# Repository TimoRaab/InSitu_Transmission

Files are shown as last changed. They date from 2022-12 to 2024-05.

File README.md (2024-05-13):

# InSitu_Transmission

Files for In-Situ Transmission Spin Coating Setup from the PhD Thesis "In-Situ Characterization of Film Formation in Solution-Processed Solar Cells" from Timo Raab, Universität Konstanz, 2022.

File setup of in-situ Data
v09+

The files are stored binary using the LabView WriteToBinaryFile function. For correct sizing of the arrays the dimension is stored additionally at the beginning of each file. 
For each measurement 4 files are stored:
_meas.spin (stores the real data)
_time.spin (stores the time of each data point (in 10us, standard from spectrometer))
_add.spin (additional data like dark and reference spectra, wavelength axis, start time …)

For using these binary files one has to know exactly how these are stored, as one is only interpreting bytes when reading them. One could open these files with any other program and let it try to interpret these files. If additional informations are stored in the LabView program, the interpretation of the read scripts has to be adjusted accordingly. 

The meas.spin stores each point as an „unsigned int 16“. One can imagine it as a black and white movie, in which spectrum is a picture containing its grey values. The size of the picture are the x and y direction. The length of the movie is frames. 
All of these values are stored at the beginning of each file as an „unsigned integer 32“. Therefore before reading the measurement data, first the 3 dimensions of the movie are read from the file. Afterwards the actual measurement data is read from the file. It is exactly x*y*frames datapoints read.
After reading, all these data is contained in a one dimensional array. This has to be reshaped to a correct 3-dimensional array. 

The time array is in labview a one dimensional array. It is also stored like the data, but only one dimension is written in front of the actual data and therefore has to be read before the data. The size has to be the same as the frames. The time is stored as an uint32 for better resolution and enough range.

The add.spin is the most complicated file, as multiple arrays and values are stored. 
3 dimensional array for the dark-spectrum (uint16)
3 dimensional array for the reference spectrum (uint16)
1 dimensional array for the wavelength (double)
single value for starttime (double)
single value for timeDiff (double)

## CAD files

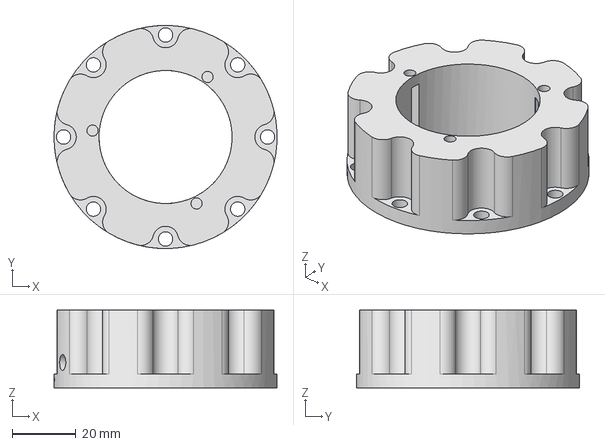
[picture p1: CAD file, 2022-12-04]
Hardware/Step/MotorHolder.stp
70.0 x 70.0 x 24.4 mm

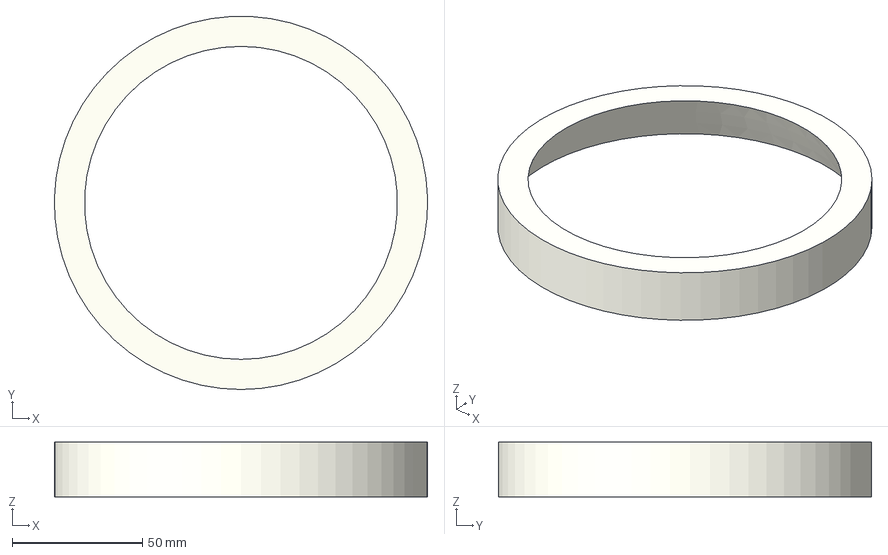
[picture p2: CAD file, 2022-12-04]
Hardware/Step/Ring.stp
143.2 x 143.2 x 21.0 mm

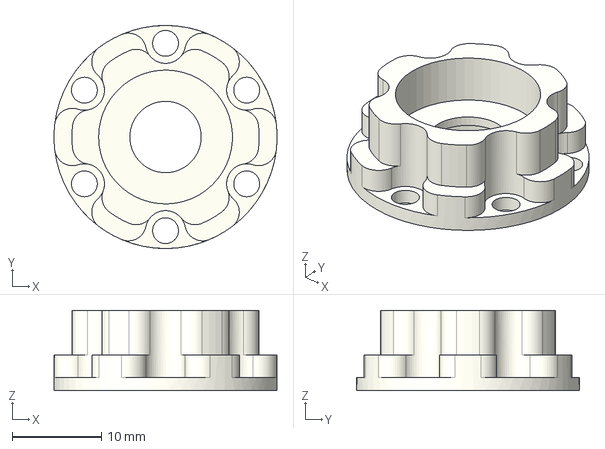
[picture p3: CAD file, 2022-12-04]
Hardware/Step/motor_top.stp
25.0 x 25.0 x 9.00 mm

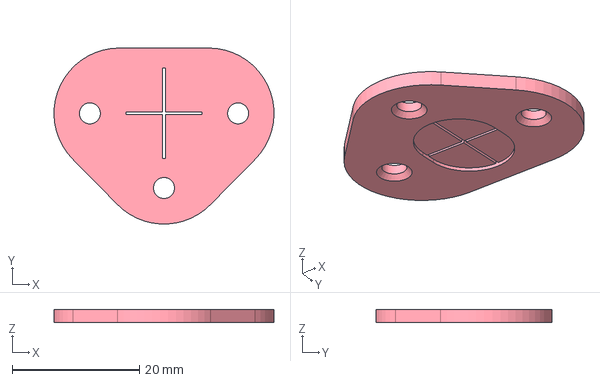
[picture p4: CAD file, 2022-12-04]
Hardware/Step/Cover.stp
34.6 x 27.7 x 2.00 mm

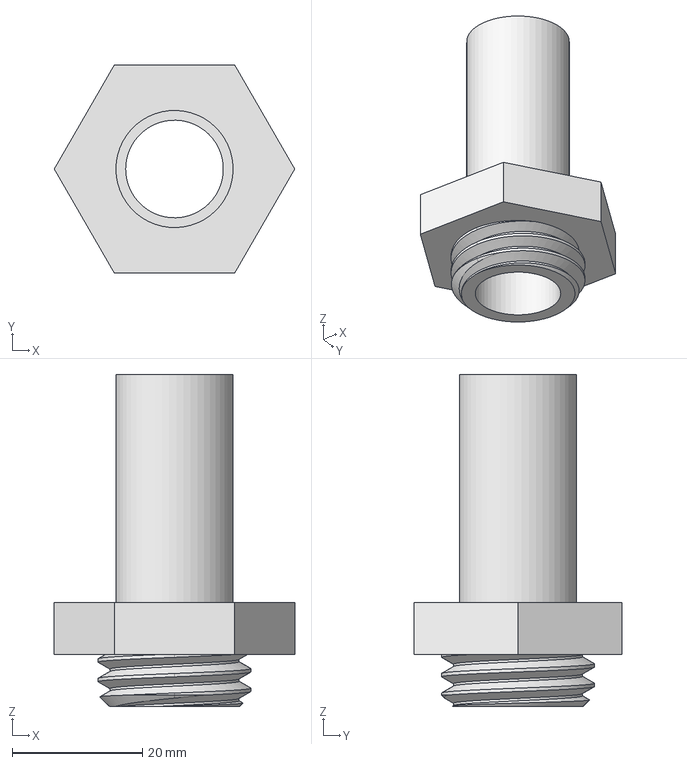
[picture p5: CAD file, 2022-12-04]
Hardware/Step/WaterAdapter.stp
37.0 x 32.0 x 51.0 mm

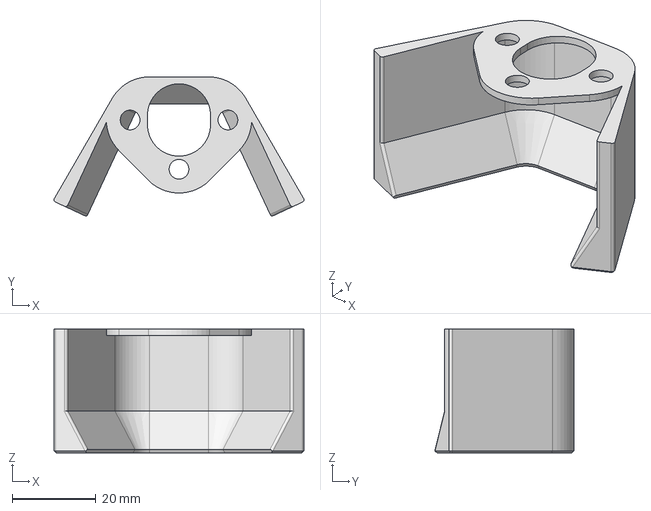
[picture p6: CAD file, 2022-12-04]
Hardware/Step/Cover_EqualPressure.stp
59.5 x 33.2 x 29.5 mm

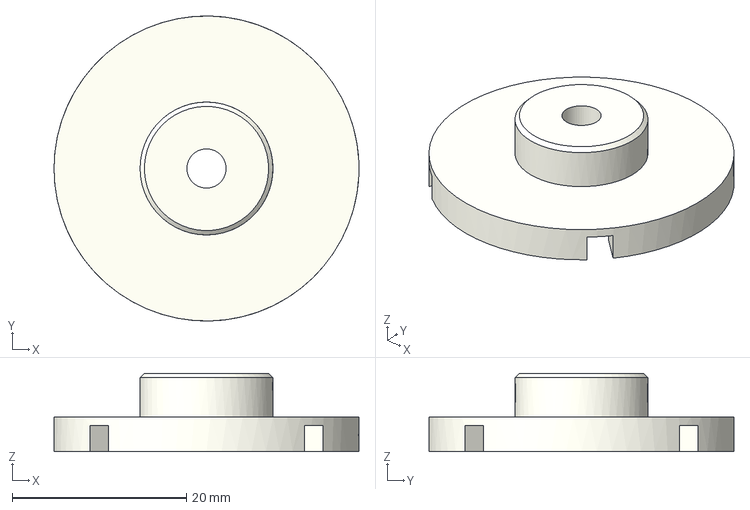
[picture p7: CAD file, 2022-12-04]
Hardware/Step/chuck_v03.stp
35.0 x 35.0 x 9.00 mm

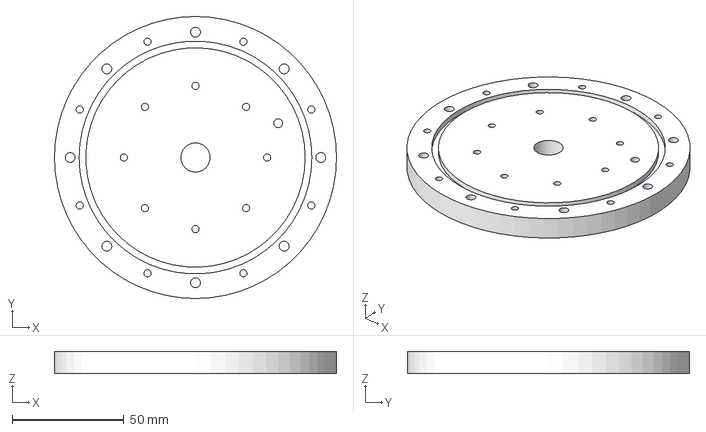
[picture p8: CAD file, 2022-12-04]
Hardware/Step/Base_Bowl_Glovebox.stp
126.0 x 126.0 x 10.0 mm

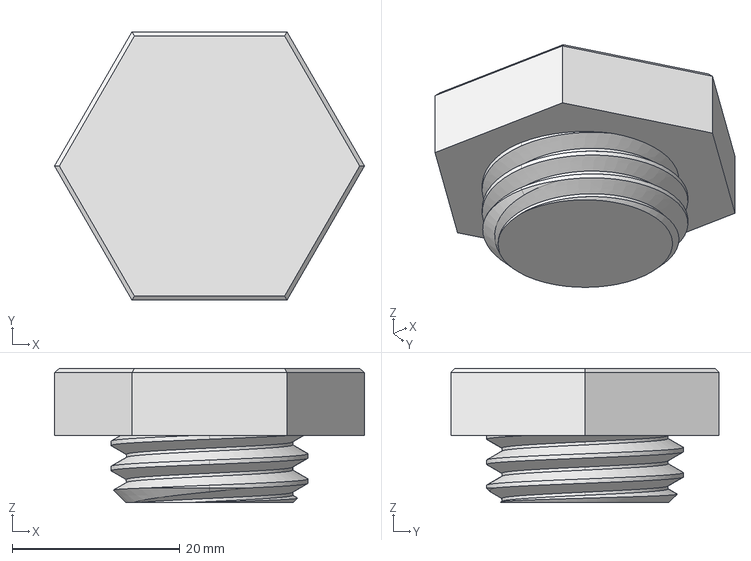
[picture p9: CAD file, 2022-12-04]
Hardware/Step/WaterAdapter_Closure.stp
37.0 x 32.0 x 16.0 mm

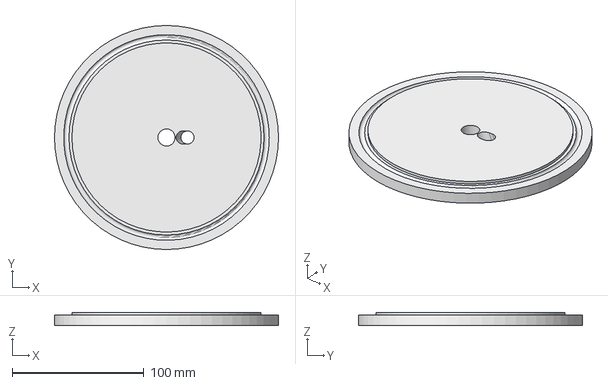
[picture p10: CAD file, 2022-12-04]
Hardware/Step/Deckel.stp
170.0 x 170.0 x 10.0 mm

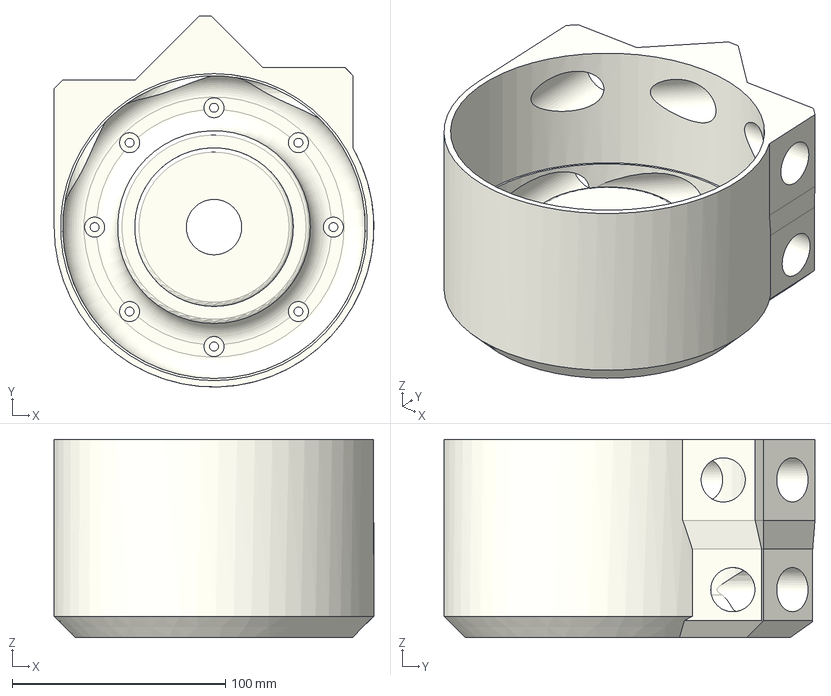
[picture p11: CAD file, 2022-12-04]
Hardware/Step/Bowl_GloveboxLike-small_ScrewingAbove.stp
150.0 x 174.0 x 93.0 mm

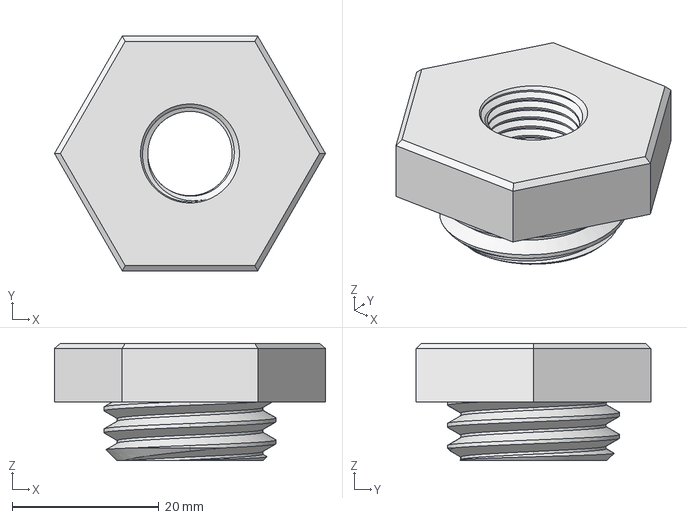
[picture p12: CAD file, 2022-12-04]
Hardware/Step/M24_2_1_4inch.stp
37.0 x 32.0 x 16.0 mm

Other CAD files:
Hardware/SpinCoaterAssembly/Base_Bowl_Glovebox.ipt
Hardware/SpinCoaterAssembly/Bowl_GloveboxLike-small_ScrewingAbove.ipt
Hardware/SpinCoaterAssembly/Cover.ipt
Hardware/SpinCoaterAssembly/Cover_EqualPressure.ipt
Hardware/SpinCoaterAssembly/Cover_Giessform.ipt
Hardware/SpinCoaterAssembly/Deckel.ipt
Hardware/SpinCoaterAssembly/M24_2_1_4inch.ipt
Hardware/SpinCoaterAssembly/MotorHolder.ipt
Hardware/SpinCoaterAssembly/OldVersions/Bowl_GloveboxLike-small_ScrewingAbove.0003.ipt
Hardware/SpinCoaterAssembly/OldVersions/Cover.0004.ipt
Hardware/SpinCoaterAssembly/OldVersions/Deckel.0004.ipt
Hardware/SpinCoaterAssembly/OldVersions/Ring.0002.ipt
Hardware/SpinCoaterAssembly/OldVersions/SpinCoaterAssembly.0003.iam
Hardware/SpinCoaterAssembly/Ring.ipt
Hardware/SpinCoaterAssembly/SpinCoaterAssembly.iam
Hardware/SpinCoaterAssembly/WaterAdapter.ipt
Hardware/SpinCoaterAssembly/WaterAdapter_Closure.ipt
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

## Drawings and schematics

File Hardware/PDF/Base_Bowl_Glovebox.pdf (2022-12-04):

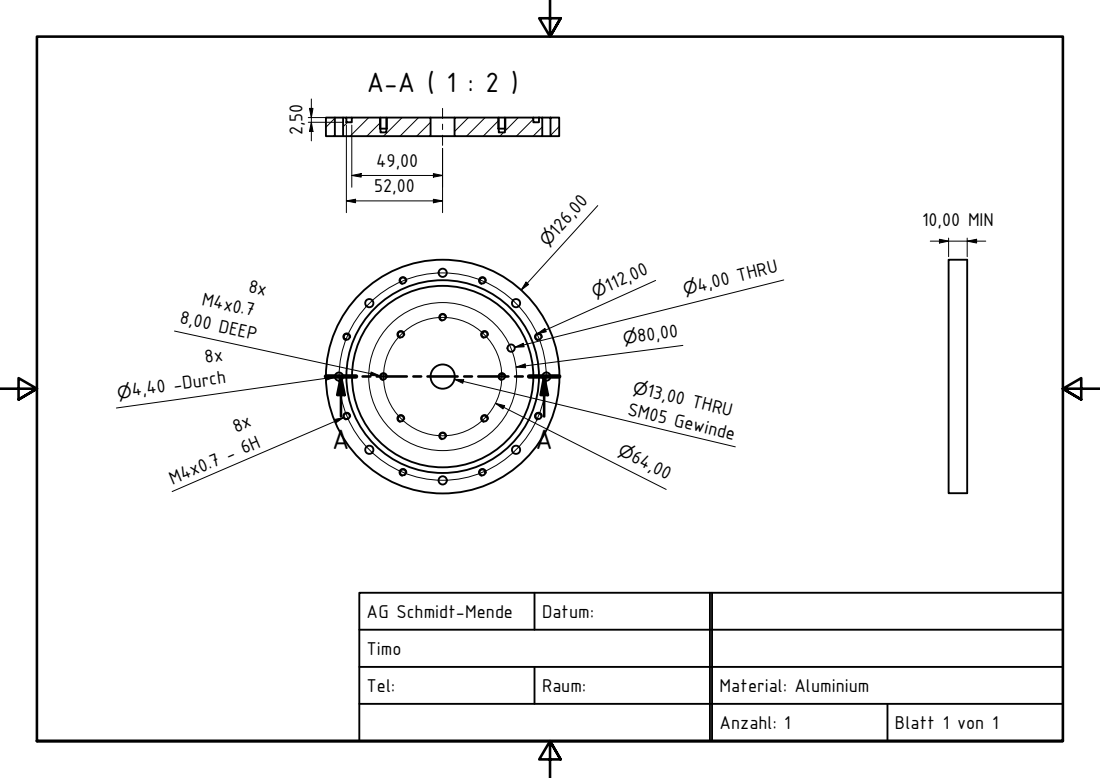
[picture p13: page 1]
10,00 MIN; 13,00 THRU 05 Gewinde; 8,00 DEEP

AG Schmidt-Mende | Datum:

Timo

Tel: | Raum: | Material: Aluminium

Anzahl: 1 | Blatt 1 von 1

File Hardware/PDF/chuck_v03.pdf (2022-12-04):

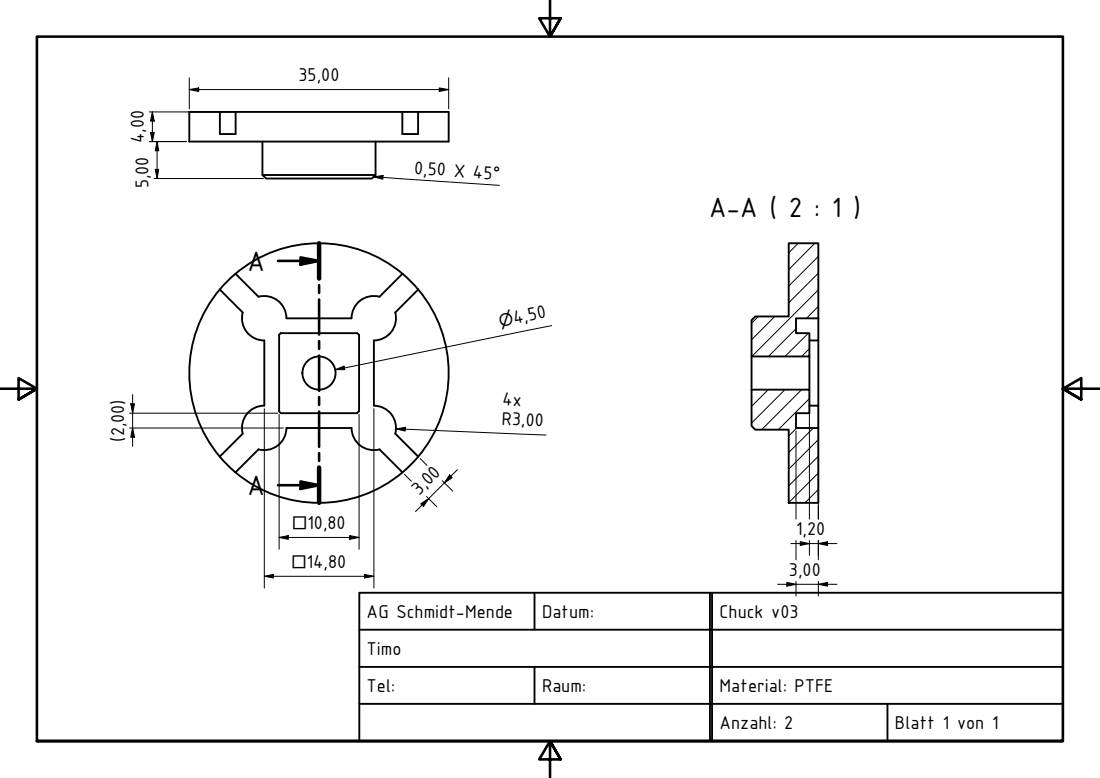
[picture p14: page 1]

AG Schmidt-Mende | Datum: | Chuck v03

Timo

Tel: | Raum: | Material: PTFE

Anzahl: 2 | Blatt 1 von 1

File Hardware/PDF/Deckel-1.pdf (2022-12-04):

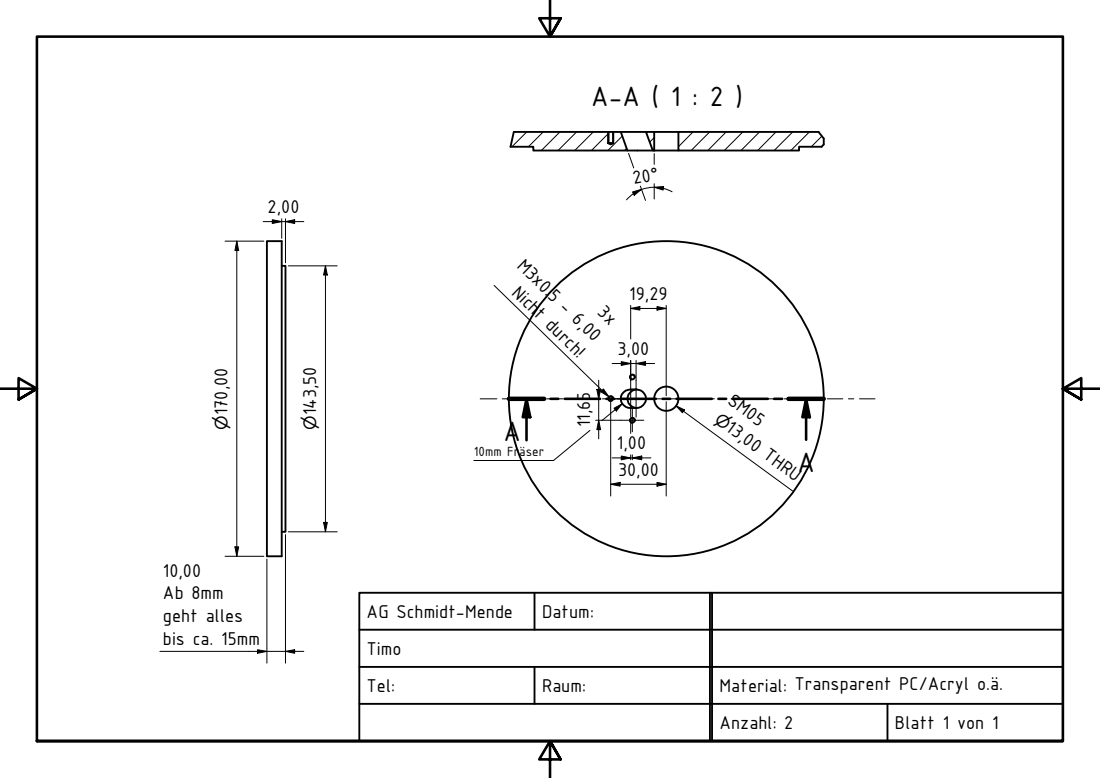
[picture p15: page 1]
Ab 8mm geht alles bis ca. 15mm; Nicht durch!; 13,00 THRU

AG Schmidt-Mende | Datum:

Timo

Tel: | Raum: | Material: Transparent PC/Acryl o..

Anzahl: 2 | Blatt 1 von 1

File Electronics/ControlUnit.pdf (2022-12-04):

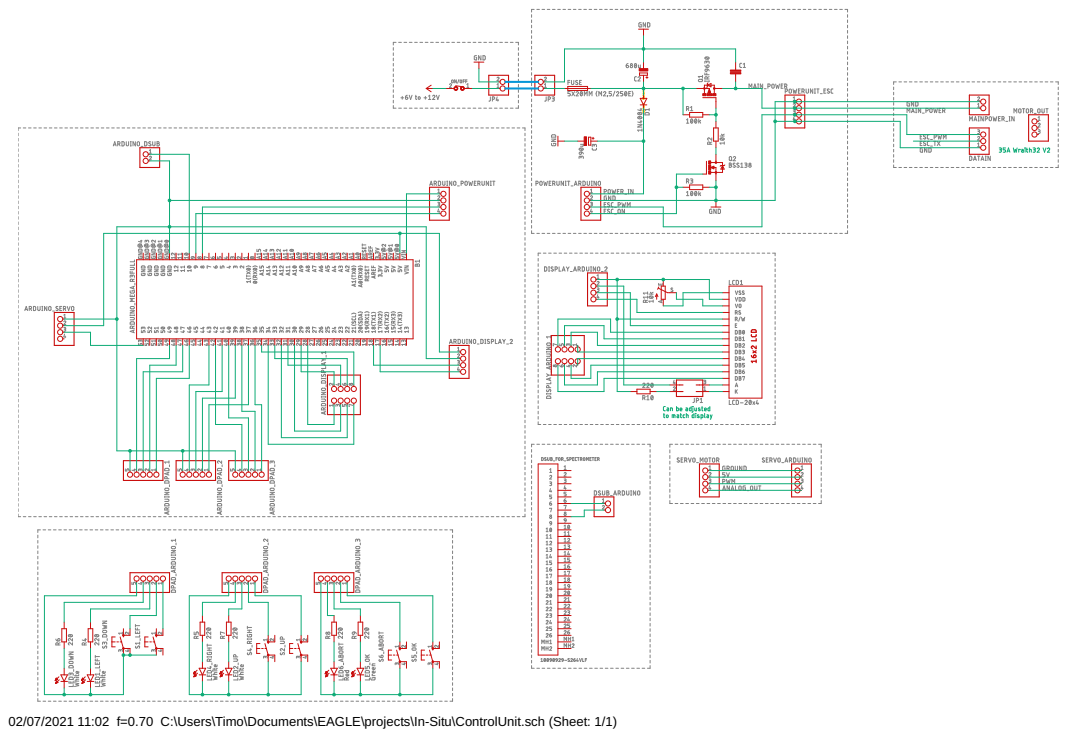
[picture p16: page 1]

02/07/2021 11:02 f=0.70 C:\Users\Timo\Documents\EAGLE\projects\In-Situ\ControlUnit.sch (Sheet: 1/1)

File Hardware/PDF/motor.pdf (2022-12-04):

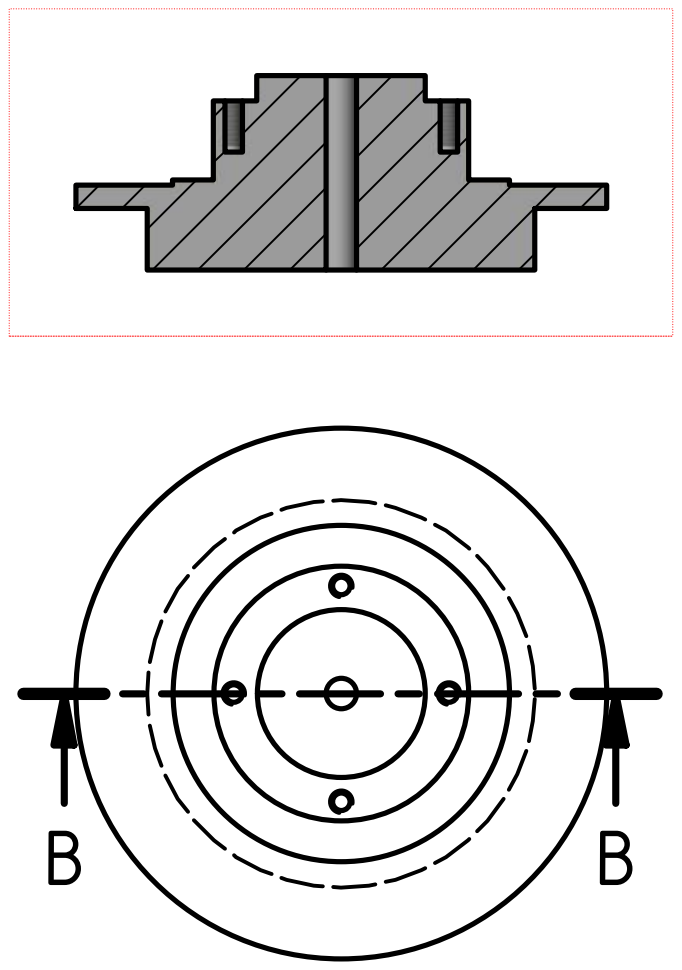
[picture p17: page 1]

Datum | Name

Gezeichn | 23.03.2020 | TimoR

Kontroll

Norm

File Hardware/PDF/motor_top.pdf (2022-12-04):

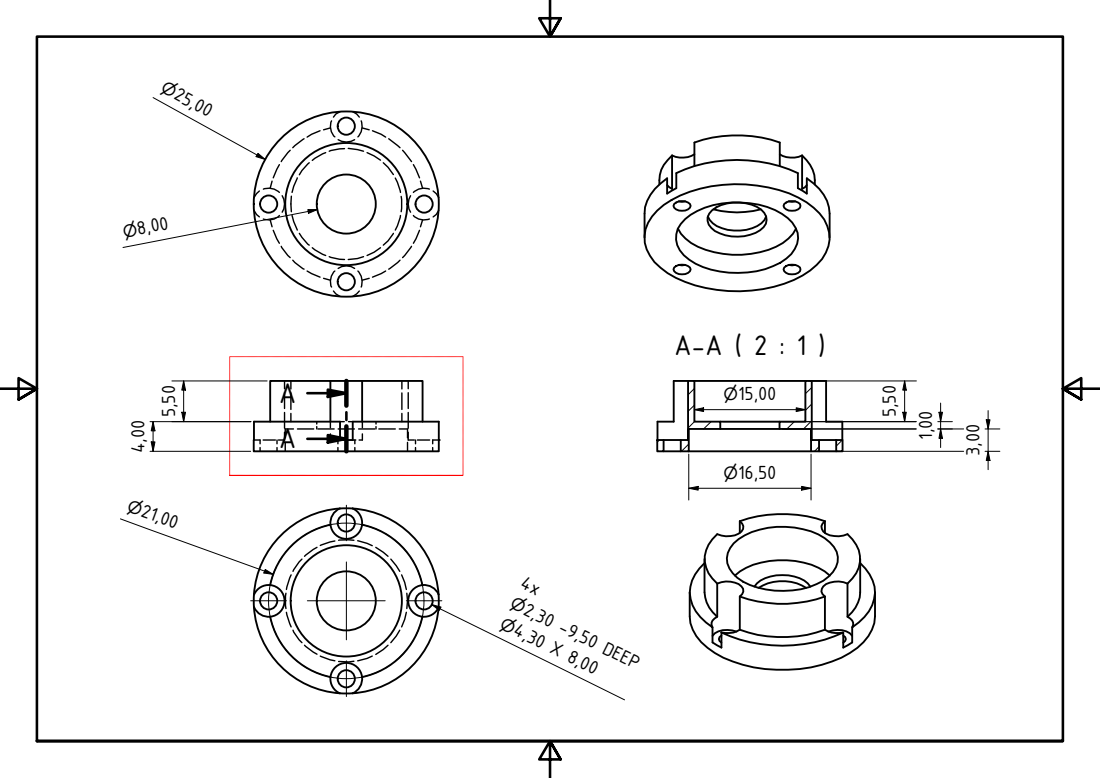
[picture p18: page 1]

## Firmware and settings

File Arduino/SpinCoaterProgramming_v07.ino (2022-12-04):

/**
  Spin Coater Control Software

  @author Timo Raab
          University of Konstanz
          Universitätsstraße 10
          78464 Konstanz
          Germany

          Timo.Raab@uni-konstanz.de

  @version v0.6

  Changes in Versions:
  v0.6  -speed of zero is now possible, steps only gets neglected if time is 0
  v0.7  -changed Servo library to superior ServoTimer2
        -Added new spin method to be able to abort the spin runShort
        -Changed run to runNormal
        -Changed string for remote program
            rem[delayValue]_[shortTime](_[speedX]_[time_X]_[accX])ntimes
            rem(+|-)\d+_\d+(_\d+_\d+_\d+)+
*/

// @TODO________________________________________________________________________
/*
 *
 */

// @Upgrade_____________________________________________________________________
/*
 * 
 */

// Libraries____________________________________________________________________

#include <Arduino.h>
#include <LiquidCrystal.h>
#include <Servo.h>
#include <Button.h>
#include <EEPROM.h>


// Definitions__________________________________________________________________

#define TERMINATOR '\n'
#define RARROW  "\x7E"
#define LARROW  "\x7F"
#define VLINE   "\x7C"
String charList[] = {
  " ", "A", "B", "C", "D", "E", "F", "G", "H", "I", "J", "K", "L", "M", "N", 
  "O", "P", "Q", "R", "S", "T", "U", "V", "W", "X", "Y", "Z",
  "0", "1", "2", "3", "4", "5", "6", "7", "8", "9"
};
unsigned int cListLen = sizeof(charList)/sizeof(charList[0]);


// Magic Numbers________________________________________________________________
// LCD configuration
const byte dispLines = 4;
const byte dispColumns = 20;
const byte rs = 17, en = 18, d0 = 34, d1 = 32, d2 = 30, d3 = 28,
    d4 = 29, d5 = 31, d6 = 33, d7 = 35;
byte currentLine = 0;
byte currentTab = 0;

// ESC configuration
const byte escPin = 8;
const byte escStartPin = 9;

// Button configuration 37 48 39 46 36 38
const byte buttonUp = 36;
const byte buttonDown = 48;
const byte buttonLeft = 46;
const byte buttonRight = 38;
const byte buttonOK = 37;
const byte buttonAbort = 39;

Button bUp = Button(buttonUp);
Button bDown = Button(buttonDown);
Button bLeft = Button(buttonLeft);
Button bRight = Button(buttonRight);
Button bOK = Button(buttonOK);
Button bAbort = Button(buttonAbort);

// LED configuration
const byte ledUp = 40;
const byte ledDown = 49;
const byte ledLeft = 47;
const byte ledRight = 42;
const byte ledOK = 41;
const byte ledAbort = 43;

// Spectrometer configuration
const byte trigger = 10;


// Shutter configuration
const byte shutterPin = 53;
const int shutterOn = 900;    
const int shutterOff = 1300;   
boolean shutterStatus = false;


// Calibration for Speed Control
// calibMethod
//    0   linear interpolation with calib
//    1   2nd order interpolation with fitValues a-c
const unsigned int calibMethod = 1;
const unsigned int calib[2][2] = {
  {1250, 396},
  {2000, 1770}
};

// Values at 25.03.2022
const float fitA = -0.0003921;
const float fitB = 5.867;
const float fitC = -5030;

// Values old
//const float fitA = -0.00008537;
//const float fitB = 5.107;
//const float fitC = -4590;


// Spin Coater Programs
// Limited to 10 at the beginning
const unsigned int maxProg = 10;
const unsigned int maxSteps = 10;
unsigned long spinSteps[maxProg][maxSteps][3];
unsigned int progNumber = 0;
String progName[maxProg];
const unsigned int maxRemote = 20;
unsigned long remoteProg[maxRemote][3];
int delayValue = 0;
unsigned long shortTime = 0;


// Menu counter
/**
 * 0    list menu
 * 1    main menu
 * 2    edit menu
 * 3    running menu
 */
byte menuCount = 0;
byte lastMenu = 0;
bool menuSwitch = true;
unsigned int displayListStart = 0;

bool killLoop = false;
bool shortLoop = false;


// ___________DO NOT EDIT till _______________
  String clLine = "";
  LiquidCrystal lcd(rs, en, d0, d1, d2, d3, d4, d5, d6, d7);
  Servo ESC;
  Servo shutter;
//_____________________________________________




// Setup Settings_______________________________________________________________

/**/
void serialSetting() {
  Serial.begin(115200);
  Serial.println("Serial Finshed");
}

/**/
void pinSetting() {
  pinMode(escStartPin, OUTPUT);
  Serial.println("pinSetting Finshed");
}

/**/
void buttonSetting() {
  pinMode(buttonUp, INPUT_PULLUP);
  pinMode(buttonDown, INPUT_PULLUP);
  pinMode(buttonLeft, INPUT_PULLUP);
  pinMode(buttonRight, INPUT_PULLUP);
  pinMode(buttonOK, INPUT_PULLUP);
  pinMode(buttonAbort, INPUT_PULLUP);
  Serial.println("buttonSetting Finshed");
}

/**/
void ledSetting() {
  pinMode(ledUp, OUTPUT);
  pinMode(ledDown, OUTPUT);
  pinMode(ledLeft, OUTPUT);
  pinMode(ledRight, OUTPUT);
  pinMode(ledOK, OUTPUT);
  pinMode(ledAbort, OUTPUT);
  digitalWrite(ledUp, HIGH);
  digitalWrite(ledDown, HIGH);
  digitalWrite(ledLeft, HIGH);
  digitalWrite(ledRight,HIGH);
  digitalWrite(ledOK, HIGH);
  digitalWrite(ledAbort, HIGH);
  Serial.println("ledSetting Finshed");
}

/**/
void lcdSetting() {
  defineClearLineString();
  lcd.begin(dispColumns, dispLines);
  lcd.setCursor(0,0);
  lcd.print("Start Up");
  lcd.setCursor(0,1);
  lcd.print("Please wait");
  Serial.println("LCDSetting Finshed");
}

/**/
void escSetting() {
  ESC.attach(escPin);
  ESC.writeMicroseconds(850);
  delay(200);
  digitalWrite(escStartPin, HIGH);
  /*ESC.writeMicroseconds(850);
  delay(200);
  ESC.writeMicroseconds(2000);
  delay(200);
  ESC.writeMicroseconds(1000);*/
  Serial.println("ESC Finshed");
}

/**/
void spectrometerSetting() {
  pinMode(trigger, OUTPUT);
  digitalWrite(trigger, LOW);
}

/**/
void shutterSetting() {
  shutter.attach(shutterPin);
  shutterClose();
  shutterStatus = false;
}

/**/
void startUp() { 
  Serial.println("Start StartUp");
  EEPROM.get(0, spinSteps);
  Serial.println("Reading Steps finished");
  //EEPROM.get(sizeof(spinSteps), progName);
}

/**/
void defineClearLineString() {
  for (int i = 0; i < dispColumns; i++) {
    clLine = clLine + " ";
  }
}

// End Setup Settings
// _____________________________________________________________________________


// Methods______________________________________________________________________

/**
 * clears line on the LCD display (writes spaces)
 * 
 * @param n   line, which should be cleared
 * 
 * @note sets cursor back to beginning of deleted line
 */
void clearLine(int n) {
  lcd.setCursor(0,n);
  lcd.print(clLine);
  lcd.setCursor(0,n);
}


/**
 * clears complete LCD display
 * 
 * @note sets cursor back to beginning of display
 */
void clearDisplay() {
  for (int i = 0; i < dispLines; i++) {
    lcd.setCursor(0,i);
    lcd.print(clLine);
  }
  lcd.setCursor(0,0);
}

/**
 * clears display at menu switch 
 */
void menuSwitchReset() {
  menuSwitch = false;
  clearDisplay();
}


/**
 * Moves shutter to specified position
 */
boolean shutterMoveTo(int position) {
  shutter.writeMicroseconds(position);
  return true;
}

/**
 * Opens shutter
 */
boolean shutterOpen() {
  return shutterMoveTo(shutterOn);
}

/**
 * Close shutter
 */
boolean shutterClose() {
  return shutterMoveTo(shutterOff);
}

boolean shutterToggle() {
  if (shutterStatus) {
    return shutterClose();
  } 
  return shutterOpen();
}

//_Menu_List____________________________________________________________________
/**
 * create menu list
 */
void createListMenu() {
  clearDisplay();
  for (int i=0; i < dispLines; i++) {
    lcd.setCursor(1,i);
    unsigned int tInt = (displayListStart + i)%maxProg;
    String temp = "Prg " + insertTrailing(String(tInt), "0", 2, true)
        + String(VLINE) + progName[tInt];
    lcd.print(temp);
  }
}

/**
 * Button Configuration for list menu
 */
void listMenuLoop() {
  createListMenu();
  lcd.setCursor(0,0);
  lcd.print(RARROW);
  currentLine = 0;
  currentTab = 0;

  while (!killLoop) {
    handleSerialInput();
    if (bDown.isPressed(false)) {
      progNumber++;
      progNumber = progNumber % maxProg;
      currentLine++;
      if (currentLine < dispLines) {
        lcd.setCursor(0,currentLine-1);
        lcd.print(" ");
        lcd.setCursor(0,currentLine);
        lcd.print(RARROW);
      } else {
        clearDisplay();
        displayListStart++;
        displayListStart = displayListStart % maxProg;
        createListMenu();
        lcd.setCursor(0,dispLines-1);
        currentLine--;
        lcd.print(RARROW);
      }
    }

    if (bUp.isPressed(false)) {
      progNumber--;
      progNumber = (progNumber + maxProg) % maxProg;
      if (currentLine != 0) {
        currentLine--;
        setMenuCursor(0,currentLine,0, currentLine+1);
      } else {
        displayListStart = (displayListStart - 1 + maxProg) % maxProg;
        createListMenu();
        lcd.setCursor(0,0);
        lcd.print(RARROW);
      }
    }

    if (bRight.isPressed(false)) {
      unsigned int temp = progNumber / 10;
      temp++;
      progNumber = temp*10;
      currentLine = 0;
      displayListStart = progNumber;
      createListMenu();
      lcd.setCursor(0,0);
      lcd.print(RARROW);
    }

    if (bLeft.isPressed(false)) {
      unsigned int temp = (progNumber+maxProg)/ 10;
      temp--;
      temp %= 10;
      progNumber = temp*10;
      currentLine = 0;
      displayListStart = progNumber;
      createListMenu();
      lcd.setCursor(0,0);
      lcd.print(RARROW);
    }

    if (bOK.isPressed(false)) {
      displayListStart = progNumber;
      menuCount = 1;  // jump to main menu
      return;
    }
  }
}

//_Menu_Main____________________________________________________________________

void prepareMainMenu(unsigned int col, unsigned int line) {
  clearDisplay();
  lcd.setCursor(1,0);
  String temp = "Prg " + insertTrailing(String(progNumber), " ", 2, true)
       + String(VLINE) + progName[progNumber];
  lcd.print(temp);
  lcd.setCursor(1,1);
  temp = "Start " + String(VLINE) + " Edit";
  lcd.print(temp);
  lcd.setCursor(1,2);
  temp = "Step 0";
  lcd.print(temp);
  updateDisplayStep(0);

  setMenuCursor(col, line, 0, 2);
}


void updateDisplayStep(unsigned int step) {
  clearLine(2);
  clearLine(3);
  lcd.setCursor(0,2);
  lcd.print(RARROW);
  lcd.setCursor(1,2);
  String temp = "Step " + String(step);
  lcd.print(temp);
  lcd.setCursor(1,3);
  temp = String(spinSteps[progNumber][step][0]) + " rpm " + VLINE + " " + 
      time2String(spinSteps[progNumber][step][1]/1000);
  lcd.print(temp);
}


void setMenuCursor(unsigned int newC, unsigned int newL, 
    unsigned int oldC, unsigned int oldL) {
  lcd.setCursor(oldC, oldL);
  lcd.print(" ");
  lcd.setCursor(newC, newL);
  lcd.print(RARROW);
}


void mainMenuLoop() {
  currentLine = 1;
  currentTab = 0;
  unsigned int tabPosition;
  unsigned int currentStep = 0;
  prepareMainMenu(0,1);

  while (!killLoop) {
    handleSerialInput();
    if (bDown.isPressed(false)) {
      unsigned int oldL = currentLine;
      unsigned int oldC = tabPosition;
      currentLine++;
      if (currentLine == dispLines-1) currentLine--;
      currentTab = 0;
      tabPosition = 0;
      setMenuCursor(tabPosition, currentLine, oldC, oldL);
    }
    if (bUp.isPressed(false)) {
      unsigned int oldL = currentLine;
      unsigned int oldC = tabPosition;
      if (currentLine != 0) currentLine--;
      currentTab = 0;
      tabPosition = 0;
      setMenuCursor(tabPosition, currentLine, oldC, oldL);
    }
    if (bRight.isPressed(false)) {
      switch (currentLine) {
        case 0:
          progNumber = (progNumber + 1) % maxProg;
          prepareMainMenu(0,0);
          break;
        case 1:
          if (currentTab == 0) {
            currentTab = 1;
            setMenuCursor(8,1,0,1);
          }
          break;
        case 2:
          currentStep = (currentStep + 1) % maxSteps; 
          updateDisplayStep(currentStep);
          break;
        default:
          break;
      }
    }
    if (bLeft.isPressed(false)) {
      switch (currentLine) {
        case 0:
          progNumber = (progNumber - 1 + maxProg) % maxProg;
          prepareMainMenu(0,0);
          break;
        case 1:
          if (currentTab == 1) {
            currentTab = 0;
            setMenuCursor(0,1,8,1);
          }
          break;
        case 2:
          currentStep = (currentStep + maxSteps - 1) % maxSteps; 
          updateDisplayStep(currentStep);
          break;
        default:
          break;
      }
    }
    if (bOK.isPressed(false)) {
      switch (currentLine) {
        case 1: 
          menuSwitch = true;
          switch (currentTab) {
            case 0:
              menuCount = 3;
              return;
            case 1:
              menuCount = 2;
              return;
          }
        default:
          break;
      }
    }
    if (bAbort.isPressed(false)) {
      menuCount = 0;
      menuSwitch = true;
      return;
    }
  }
}



//_Menu_Edit____________________________________________________________________
void prepareEditMenu() {
  clearDisplay();
  lcd.setCursor(1,0);
  String temp = "Prg " + insertTrailing(String(progNumber), " ", 2, true)
       + String(VLINE) + progName[progNumber];
  lcd.print(temp);

  lcd.setCursor(1,1);
  lcd.print("Step  0");

  temp = insertTrailing(String(spinSteps[progNumber][0][0]), "0", 4, true)
          + "rpm" + String(VLINE);
  temp = temp + " " + time2String(spinSteps[progNumber][0][1]/1000);
  lcd.setCursor(1,2);
  lcd.print(temp);

  lcd.setCursor(1,3);
  lcd.print("Finish " + String(VLINE) + " Abort");

  lcd.setCursor(0,0);
  lcd.print(RARROW);
}



void editMenuLoop() {
  currentLine = 0;
  currentTab = 0;
  unsigned int tabPosition = 0;
  unsigned int currentStep = 0;

  unsigned long spinStepsTemp[maxSteps][2];
    for (int i = 0; i < maxSteps; i++) {
      spinStepsTemp[i][0] = spinSteps[progNumber][i][0];
      spinStepsTemp[i][1] = spinSteps[progNumber][i][1];
    }
  String nameTemp = progName[progNumber];
  
  prepareEditMenu();

  bool buttonLoop = true;
  while (buttonLoop) {
    //handleSerialInput(); Deactivated to not interrupt changing settings
    if (bDown.isPressed(false)) {
      unsigned int oldL = currentLine;
      unsigned int oldC = tabPosition;
      currentLine ++;
      if (currentLine == dispLines) currentLine--;
      if (currentLine == 2) {
        if (currentTab == 0) {
          tabPosition = 0;
        }
        if (currentTab == 1) {
          tabPosition = 9;
        }
      }
      setMenuCursor(tabPosition, currentLine, oldC, oldL);
    }
    if (bUp.isPressed(false)) {
      unsigned int oldL = currentLine;
      unsigned int oldC = tabPosition;
      if (currentLine != 0) currentLine--;
      if (currentLine == 1) {
        tabPosition = 0;
      }
      setMenuCursor(tabPosition, currentLine, oldC, oldL);
    }
    if (bRight.isPressed(false)) {
      if (currentLine == 2 || currentLine == 3) {
        if (currentTab == 0) {
          currentTab = 1;
          unsigned int oldL = currentLine;
          unsigned int oldC = tabPosition;
          tabPosition = 9;
          setMenuCursor(tabPosition, currentLine, oldC, oldL);
        }
      }
      if (currentLine == 1) {
        currentStep = (currentStep + 1) % maxSteps;
        updateStepEditMenu(currentStep, spinStepsTemp);
      }
    }
    if (bLeft.isPressed(false)) {
      if (currentLine == 2 || currentLine == 3) {
        if (currentTab == 1) {
          currentTab = 0;
          unsigned int oldL = currentLine;
          unsigned int oldC = tabPosition;
          tabPosition = 0;
          setMenuCursor(tabPosition, currentLine, oldC, oldL);
        }
      }
      if (currentLine == 1) {
        currentStep = (currentStep - 1 + maxSteps) % maxSteps;
        updateStepEditMenu(currentStep, spinStepsTemp);
      }
    }
    if (bOK.isPressed(false)) {
      switch (currentLine) {
        case 0: {  //change program Name
          String temp = nameTemp;
          lcd.setCursor(8,0);
          lcd.cursor();
          unsigned int posOffset = 8;
          unsigned int pos = 0;
          unsigned int possibleLength = dispColumns-posOffset;
          String arrTemp[possibleLength];
          for (unsigned int i = 0; i < possibleLength; i++) {
            arrTemp[i] = temp.substring(i,i);
          }
          while (true) {
            if (bDown.isPressed(false)) {
              int charNumber = locateInCharList(arrTemp[pos]);
              charNumber = (charNumber - 1 + cListLen) % cListLen;
              arrTemp[pos] = charList[charNumber];
              lcd.print(charList[charNumber]);
              lcd.setCursor(pos + posOffset, 0);
            }
            if (bUp.isPressed(false)) {
              int charNumber = locateInCharList(arrTemp[pos]);
              charNumber = (charNumber + 1) % cListLen;
              arrTemp[pos] = charList[charNumber];
              lcd.print(charList[charNumber]);
              lcd.setCursor(pos + posOffset, 0);
            }
            if (bRight.isPressed(false)) {
              lcd.setCursor((pos+1) % possibleLength + posOffset,0);
              pos = (pos+1) % possibleLength;
            }
            if (bLeft.isPressed(false)) {
              lcd.setCursor((possibleLength+pos-1) % possibleLength + posOffset,0);
              pos = (possibleLength+pos-1) % possibleLength;
            }
            if (bOK.isPressed(false)) {
              lcd.noCursor();
              lcd.setCursor(0,0);
              temp = "";
              for (int i = 0; i < possibleLength; i++) {
                temp += arrTemp[i];
              }
              nameTemp = temp;
              break;
            }
            if (bAbort.isPressed(false)) {
              lcd.noCursor();
              lcd.setCursor(0,0);
              break;
            }
          }
          break;
        }
        case 2: {  // change speed or time
          if (currentTab == 0) { //change rpm
            unsigned int save = spinStepsTemp[currentStep][0];
            int maxDigit = 4;
            unsigned int spinTemp[maxDigit];

            for (int i = maxDigit-1; i >= 0; i--) {
              spinTemp[i] = save % 10;
              save /= 10;
            }

            save = spinStepsTemp[currentStep][0];
            lcd.setCursor(1,2);
            lcd.cursor();
            unsigned int pos = 0;
            unsigned int posOffset = 1;
            unsigned int possibleLength = 4;

            while (true) {
              if (bDown.isPressed(false)) {
                spinTemp[pos] = (spinTemp[pos] + 10 - 1) % 10;
                lcd.print(spinTemp[pos]);
                lcd.setCursor(pos+posOffset,2);
              }
              if (bUp.isPressed(false)) {
                spinTemp[pos] = (spinTemp[pos] + 1) % 10;
                lcd.print(spinTemp[pos]);
                lcd.setCursor(pos+posOffset,2);
              }
              if (bRight.isPressed(false)) {
                lcd.setCursor((pos+1) % possibleLength + posOffset,2);
                pos = (pos+1) % possibleLength;
              }
              if (bLeft.isPressed(false)) {
                lcd.setCursor((possibleLength+pos-1) % possibleLength + posOffset, 2);
                pos = (possibleLength+pos-1) % possibleLength;
              }
              if (bOK.isPressed(false)) {
                lcd.noCursor();
                lcd.setCursor(0,2);
                unsigned int factor = 1;
                spinStepsTemp[currentStep][0] = 0;
                for (int i = maxDigit - 1; i >= 0; i--) {
                  spinStepsTemp[currentStep][0] += spinTemp[i]*factor;
                  factor *= 10;
                }
                break;
              }
              if (bAbort.isPressed(false)) {
                lcd.setCursor(1,2);
                lcd.print(insertTrailing(
                  String(spinStepsTemp[currentStep][0]), "0", 4, true));
                lcd.noCursor();
                lcd.setCursor(0,2);
                break;
              }
            }
          }
          if (currentTab == 1) { // change Time
            unsigned int save = spinStepsTemp[currentStep][1]/1000;
            // calculate digits
            unsigned long spinTemp[4];
            spinTemp[0] = (save/60) / 10;
            spinTemp[1] = (save/60) % 10;
            spinTemp[2] = (save%60) / 10;
            spinTemp[3] = (save%60) % 10;

            lcd.setCursor(10,2);
            lcd.cursor();
            unsigned int pos = 0;
            unsigned int posOffset = 10;
            unsigned int possibleLength = 4;
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
void loop() {
  Serial.println("loop");
  if (lastMenu != menuCount) menuSwitchReset();
  killLoop = false;
  clearDisplay();
  switch (menuCount) {
    case 0:
      listMenuLoop(); 
      break;
    case 1:
      mainMenuLoop();
      break;
    case 2:
      editMenuLoop();
      break;
    case 3:
      runMenu();
      break;
    default:
      //errorLoop();
      break;
  }
}
//EOF
